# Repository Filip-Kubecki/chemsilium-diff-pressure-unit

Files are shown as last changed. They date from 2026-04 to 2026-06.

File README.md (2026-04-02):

# Pressure Measurement Unit - Chemsilium

A differential pressure acquisition system developed for the **Chemsilium Science Club**. This project integrates a **BMP280** (for ambient barometric pressure as calibration point) and dual *MPXM2202GS/AS* setup for differential pressure measurement.

## Repository Structure

The project is organized into four main branches to ensure maintainability:

* **`/hardware`**: Contains **KiCad** PCB and electronic design files.
  <!-- * `sch/`: Schematic diagrams. -->
  <!-- * `pcb/`: Board layout and routing. -->
  <!-- * `fabrication/`: Production-ready Gerbers, BOM (Bill of Materials), and CPL files. -->
* **`/firmware`**: Source code for the **Arduino/C++** embedded system.
  * Handles I2C communication with sensors.
  * Manages data packet formatting for serial transmission (using UART).
* **`/software`**: Desktop application scripts for data visualization and logging.
  * Real-time graphing of pressure trends.
  * CSV logging for post-experimental analysis.
* **`/docs`**: Technical documentation, including user manual with setup, maintenance and use explanations.

---

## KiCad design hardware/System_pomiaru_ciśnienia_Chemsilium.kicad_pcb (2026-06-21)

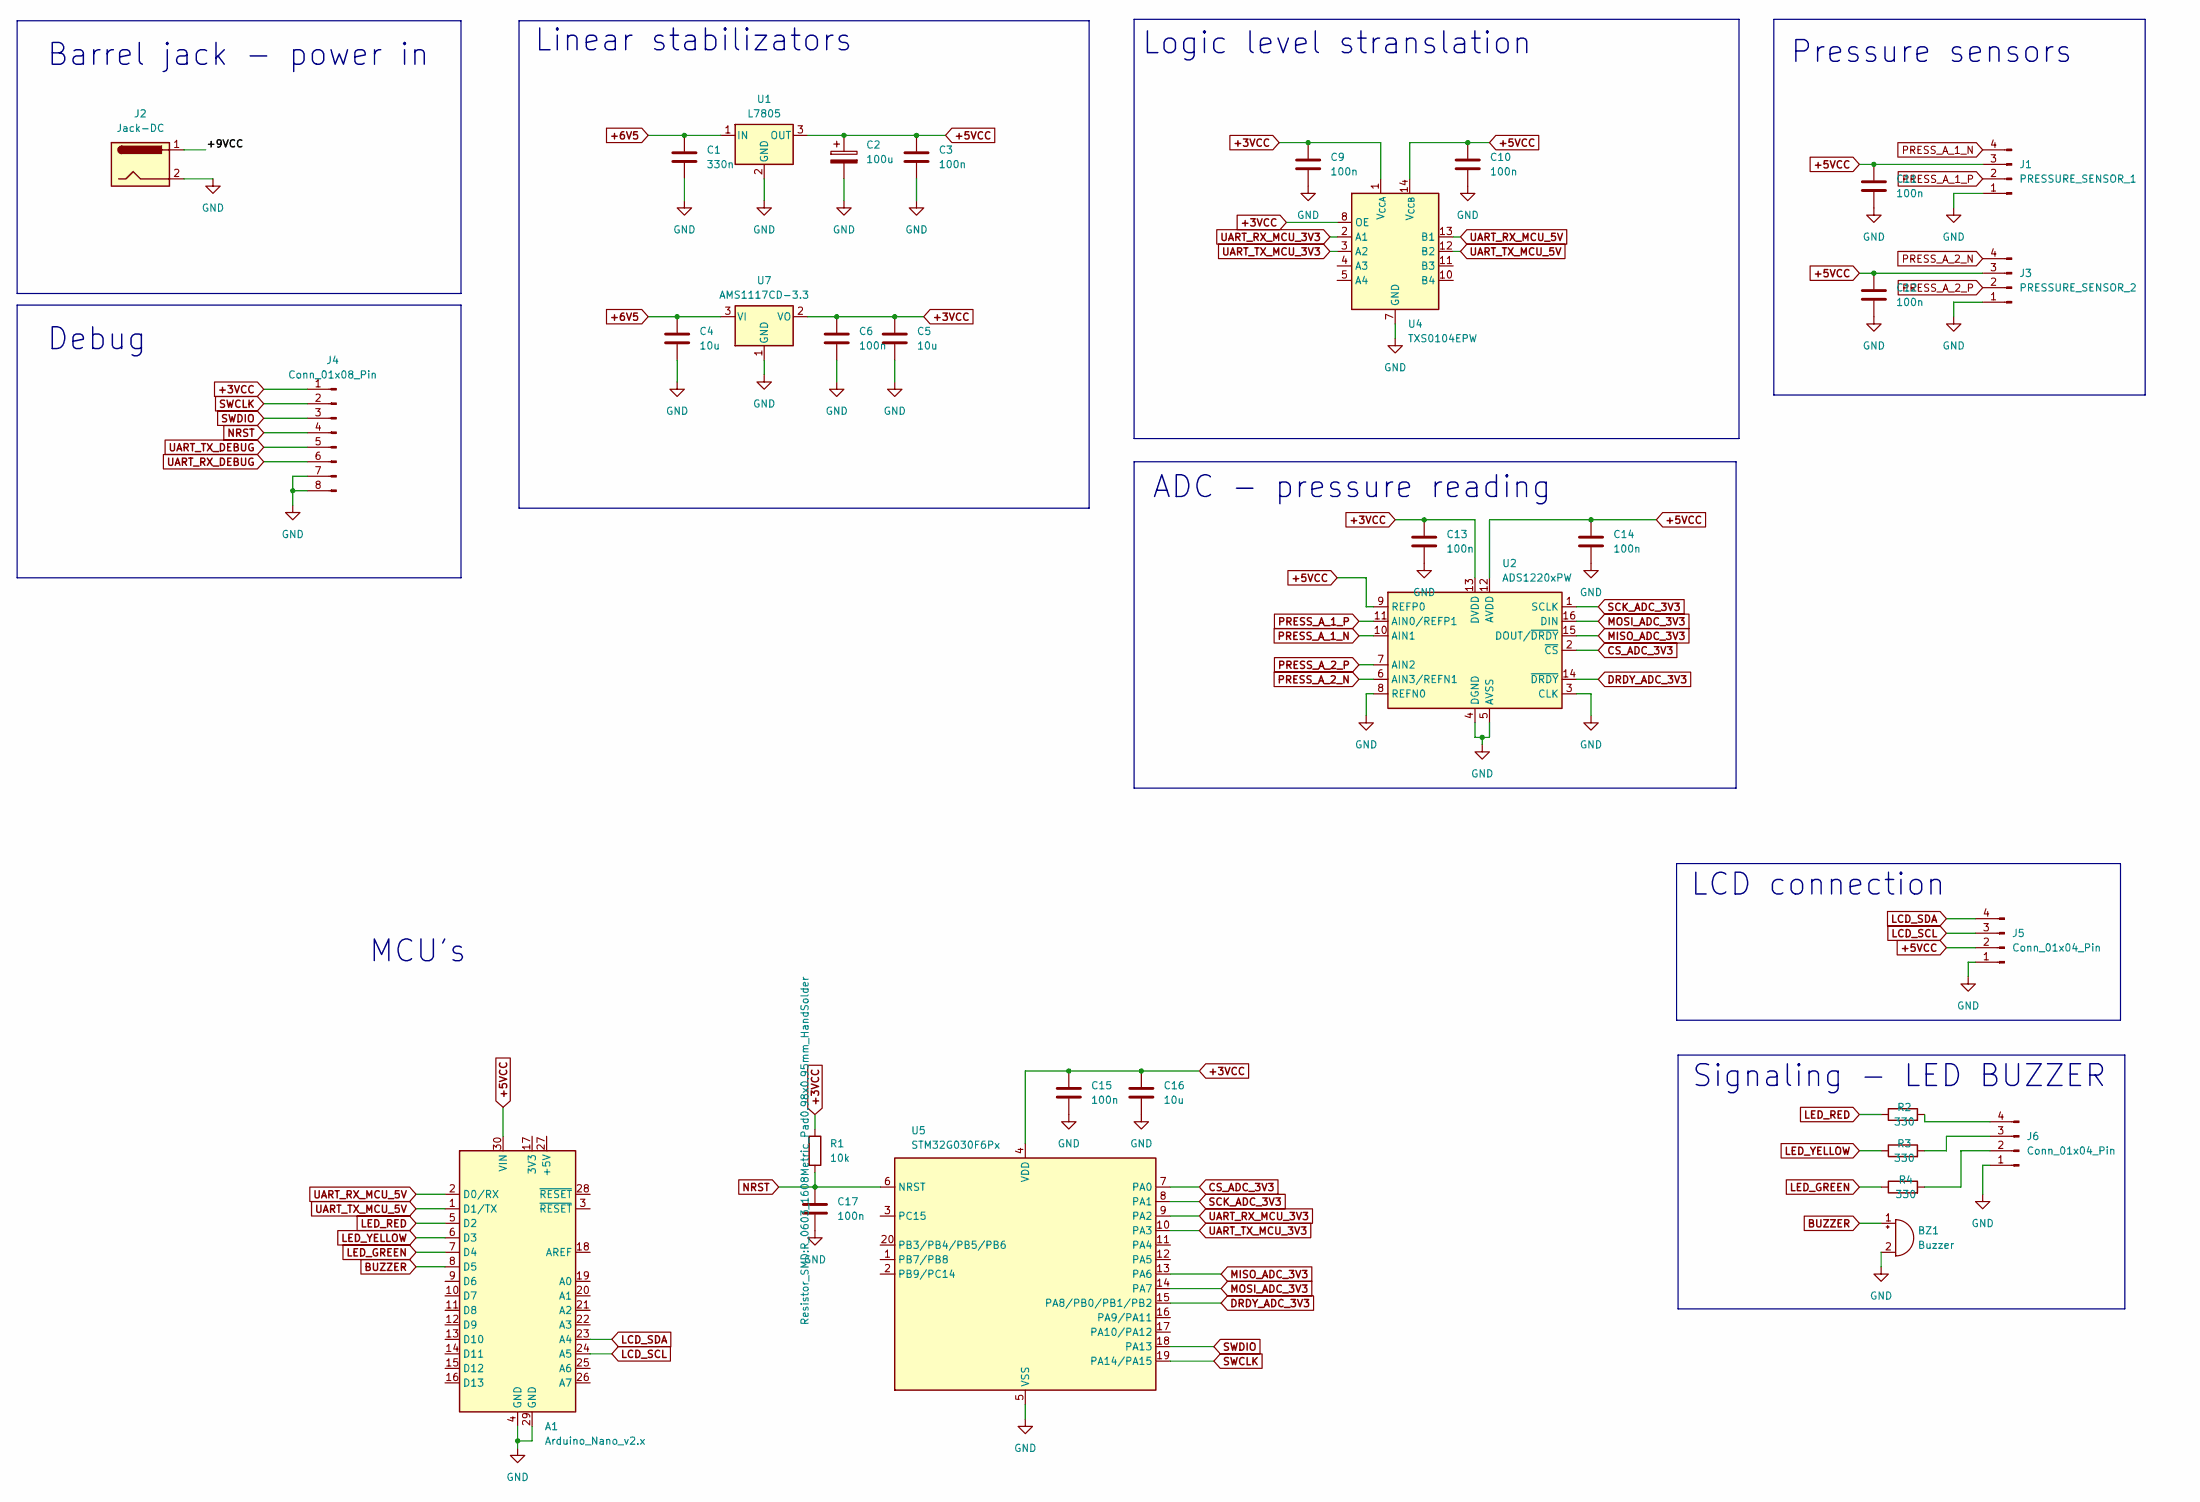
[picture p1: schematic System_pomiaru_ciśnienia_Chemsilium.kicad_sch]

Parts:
A1: Arduino_Nano_v2.x; Arduino_Nano
BZ1: Buzzer; Buzzer_12x9.5RM7.6
C1: 330n; CP_Radial_Tantal_D4.5mm_P2.50mm
C2: 100u; CP_Radial_D8.0mm_P3.80mm
C3, C6, C9, C10, C11, C12, C13, C14, C15, C17: 100n; C_0603_1608Metric_Pad1.08x0.95mm_HandSolder
C4, C5, C16: 10u; C_0805_2012Metric_Pad1.18x1.45mm_HandSolder
J1: PRESSURE_SENSOR_1; mpx2202
J2: Jack-DC; BarrelJack_CUI_PJ-102AH_Horizontal
J3: PRESSURE_SENSOR_2; mpx2202
J4: Conn_01x08_Pin; PinHeader_2x04_P2.54mm_Vertical
J5, J6: Conn_01x04_Pin; PinHeader_1x04_P2.54mm_Vertical
R1: 10k; R_0603_1608Metric_Pad0.98x0.95mm_HandSolder
R2, R3, R4: 330; R_Axial_DIN0207_L6.3mm_D2.5mm_P2.54mm_Vertical
U1: L7805; TO-220-3_Vertical
U2: ADS1220xPW; TSSOP-16_4.4x5mm_P0.65mm
U4: TXS0104EPW; TSSOP-14_4.4x5mm_P0.65mm
U5: STM32G030F6Px; TSSOP-20_4.4x6.5mm_P0.65mm
U7: AMS1117CD-3.3; TO-252-3_TabPin2

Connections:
+3VCC: C5.1, C6.1, C9.1, C13.1, C15.1, C16.1, J4.1, R1.1, U2.13 (DVDD), U4.1 (V_{CCA}), U4.8 (OE), U5.4 (VDD), U7.2 (VO)
+5VCC: A1.30 (VIN), C2.1, C3.1, C10.1, C11.1, C12.1, C14.1, J1.3, J3.3, J5.2, U1.3 (OUT), U2.9 (REFP0), U2.12 (AVDD), U4.14 (V_{CCB})
+6V5: C1.1, C4.1, U1.1 (IN), U7.3 (VI)
/+9VCC: J2.1
BUZZER: A1.8 (D5), BZ1.1 (+)
CS_ADC_3V3: U2.2 (~CS), U5.7 (PA0)
DRDY_ADC_3V3: U2.14 (~DRDY), U5.15 (PA8/PB0/PB1/PB2)
GND: A1.4 (GND), A1.29 (GND), BZ1.2 (-), C1.2, C2.2, C3.2, C4.2, C5.2, C6.2, C9.2, C10.2, C11.2, C12.2, C13.2, C14.2, C15.2, C16.2, C17.2, J1.1, J2.2, J3.1, J4.7, J4.8, J5.1, J6.1, U1.2 (GND), U2.3 (CLK), U2.4 (DGND), U2.5 (AVSS), U2.8 (REFN0), U4.7 (GND), U5.5 (VSS), U7.1 (GND)
LCD_SCL: A1.24 (A5), J5.3
LCD_SDA: A1.23 (A4), J5.4
LED_GREEN: A1.7 (D4), R4.1
LED_RED: A1.5 (D2), R2.1
LED_YELLOW: A1.6 (D3), R3.1
MISO_ADC_3V3: U2.15 (DOUT/~DRDY), U5.13 (PA6)
MOSI_ADC_3V3: U2.16 (DIN), U5.14 (PA7)
NRST: C17.1, J4.4, R1.2, U5.6 (NRST)
unnamed: J6.2, R4.2
unnamed: J6.3, R3.2
unnamed: J6.4, R2.2
PRESS_A_1_N: J1.4, U2.10 (AIN1)
PRESS_A_1_P: J1.2, U2.11 (AIN0/REFP1)
PRESS_A_2_N: J3.4, U2.6 (AIN3/REFN1)
PRESS_A_2_P: J3.2, U2.7 (AIN2)
SCK_ADC_3V3: U2.1 (SCLK), U5.8 (PA1)
SWCLK: J4.2, U5.19 (PA14/PA15)
SWDIO: J4.3, U5.18 (PA13)
UART_RX_DEBUG: J4.6
UART_RX_MCU_3V3: U4.2 (A1), U5.9 (PA2)
UART_RX_MCU_5V: A1.2 (D0/RX), U4.13 (B1)
UART_TX_DEBUG: J4.5
UART_TX_MCU_3V3: U4.3 (A2), U5.10 (PA3)
UART_TX_MCU_5V: A1.1 (D1/TX), U4.12 (B2)

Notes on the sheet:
Linear stabilizators
LCD connection
Pressure sensors
Debug
MCU's
ADC - pressure reading
Barrel jack - power in
Signaling - LED BUZZER
Logic level stranslation

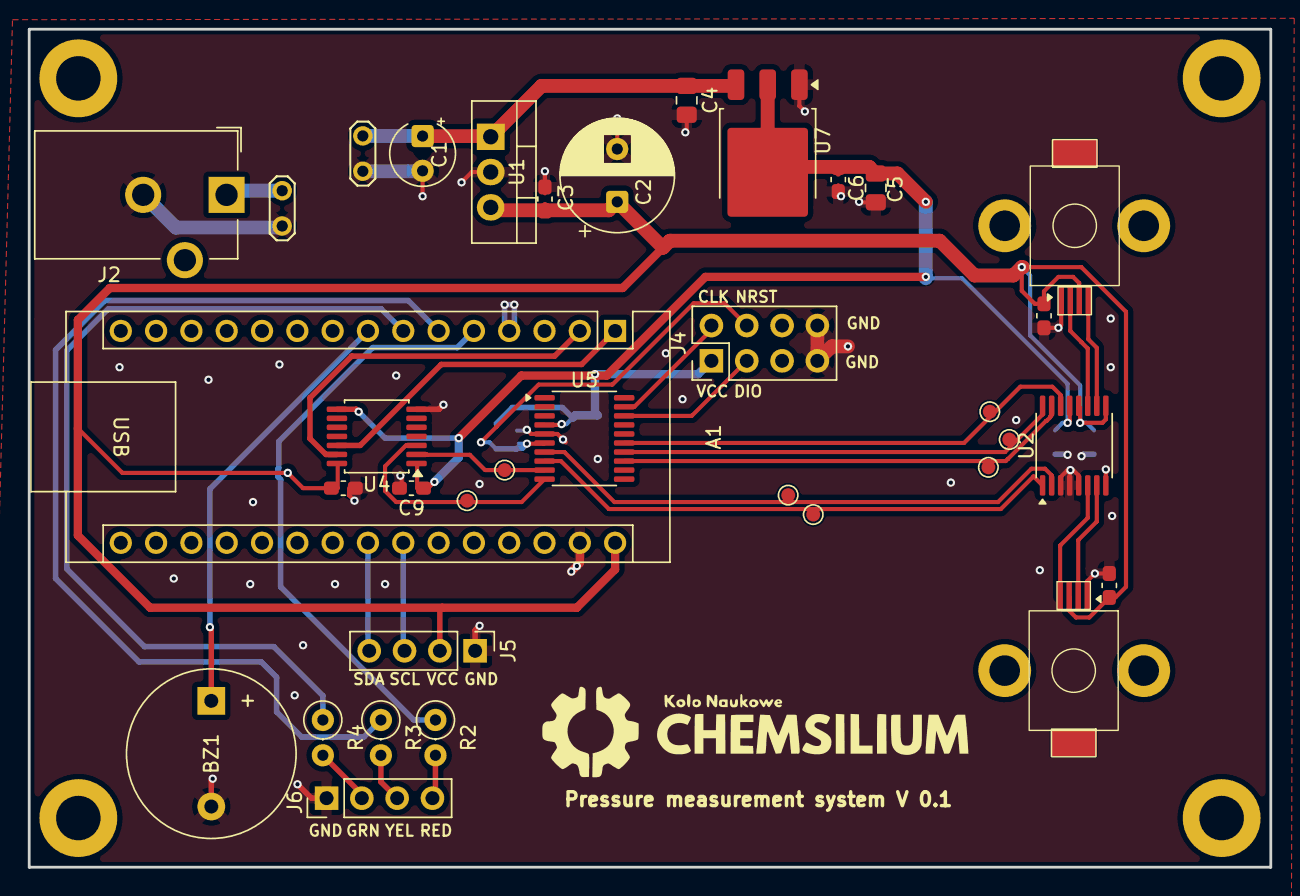
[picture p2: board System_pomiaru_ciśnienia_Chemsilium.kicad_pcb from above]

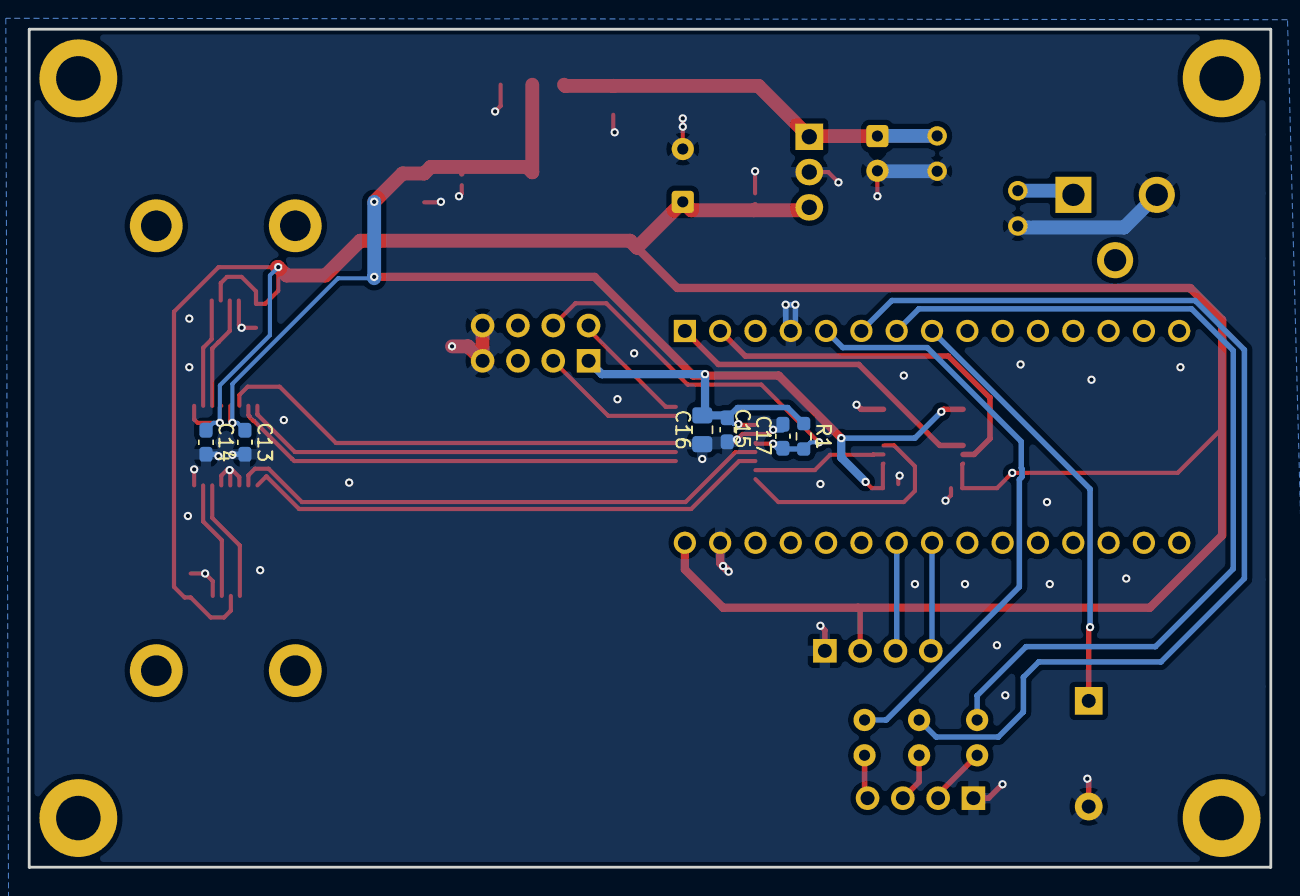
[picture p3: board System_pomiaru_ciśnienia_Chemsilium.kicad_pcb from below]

Board: 2 copper layers, 89.3 x 60.3 mm, 32 parts (6 on the bottom side), 29 nets.

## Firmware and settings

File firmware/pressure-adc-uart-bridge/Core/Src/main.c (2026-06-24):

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
/* Includes ------------------------------------------------------------------*/
#include "main.h"

/* USER CODE BEGIN Includes */
  #include <string.h>
  #include <stdlib.h>

  #include "ADS1220IPWR.h"
/* USER CODE END Includes */

SPI_HandleTypeDef hspi1;

UART_HandleTypeDef huart2;

void SystemClock_Config(void);
static void MX_GPIO_Init(void);
static void MX_USART2_UART_Init(void);
static void MX_SPI1_Init(void);
/* USER CODE BEGIN 0 */

  void Send24BitPacket(uint32_t ch1, uint32_t ch2) {
      uint8_t frame[10];
      
      frame[0] = 0xDE;
      frame[1] = 0xAD;
      
      frame[2] = (uint8_t)(ch1 >> 16);
      frame[3] = (uint8_t)(ch1 >> 8);
      frame[4] = (uint8_t)(ch1);
      
      frame[5] = (uint8_t)(ch2 >> 16);
      frame[6] = (uint8_t)(ch2 >> 8);
      frame[7] = (uint8_t)(ch2);
      
      frame[8] = 0xBE;
      frame[9] = 0xEF;
      
      HAL_UART_Transmit(&huart2, frame, 10, 100);
  }
/* USER CODE END 0 */

/**
  * @brief  The application entry point.
  * @retval int
  */
int main(void)
{

  /* MCU Configuration--------------------------------------------------------*/

  /* Reset of all peripherals, Initializes the Flash interface and the Systick. */
  HAL_Init();

  /* Configure the system clock */
  SystemClock_Config();

  /* Initialize all configured peripherals */
  MX_GPIO_Init();
  MX_USART2_UART_Init();
  MX_SPI1_Init();
  /* USER CODE BEGIN 2 */

  srand(HAL_GetTick());

  ADS1220_Init(&hspi1);
  ADS1220_Reset();
  ADS1220_Configure();

  /* USER CODE END 2 */

  /* Infinite loop */
  /* USER CODE BEGIN WHILE */
  while (1)
  {
    /* USER CODE END WHILE */

    /* USER CODE BEGIN 3 */
    int32_t raw_ch1 = 0, raw_ch2 = 0;

    ADS1220_SelectChannel(ADS1220_CHANNEL_1);
    if (ADS1220_WaitForData(20) == HAL_OK) {
        raw_ch1 = ADS1220_ReadData();
    }

    ADS1220_SelectChannel(ADS1220_CHANNEL_2);
    if (ADS1220_WaitForData(20) == HAL_OK) {
        raw_ch2 = ADS1220_ReadData();
    }

    float voltage_ch1_mV = ADS1220_RawToVoltage_mV(raw_ch1);
    float voltage_ch2_mV = ADS1220_RawToVoltage_mV(raw_ch2);

    float pressure_ch1_Pa = ADS1220_VoltageToPressure_Pa(voltage_ch1_mV);
    float pressure_ch2_Pa = ADS1220_VoltageToPressure_Pa(voltage_ch2_mV);

    Send24BitPacket((uint32_t)pressure_ch1_Pa, (uint32_t)pressure_ch2_Pa);
    HAL_Delay(1);
  }
  /* USER CODE END 3 */
}

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


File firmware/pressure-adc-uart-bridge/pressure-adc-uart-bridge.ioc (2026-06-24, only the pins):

Mcu.UserName=STM32G030F6Px
PA0.GPIO_Label=SPI1_CS
PA0.Signal=GPIO_Output
PA1.Signal=SPI1_SCK
PA2.Signal=USART2_TX
PA3.Signal=USART2_RX
PA6.Signal=SPI1_MISO
PA7.Signal=SPI1_MOSI
PB0.Signal=GPIO_Input

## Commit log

2026-04-02 [POC] Basic measurement for MX2202 with "calibration"
    Backup of old files used for fast check of MXP2202 sensor.
2026-04-02 [POC] Backup of test PCB for MPX2202 developement
    This PCB is prototype used for ease of testing MPX2202 sensors. Board
    already has differential path for analog outputs and ADS1X015 mounted on
    it. It is easy to etch in home design.
    [System_pomiaru_ciśnienia_Chemsilium.kicad_pcb, System_pomiaru_ciśnienia_Chemsilium.kicad_sch]
2026-06-21 [feat] Initial test design for differential pressure sensor PCB
    Initial PCB prototype for differential pressure measurement device.
    Identified issues for future iterations:
    - UART conflict between STM32 and Arduino Nano.
    - Incorrect footprint for MPXM2202 sensor (pitch too small).
    - Missing dedicated header for BMP280.
    - Insufficient expansion pins (GPIOs for encoder).
    - Integrated step-down converter requirement (current version lacks
    onboard integration).
    [System_pomiaru_ciśnienia_Chemsilium.kicad_pcb, System_pomiaru_ciśnienia_Chemsilium.kicad_sch]
2026-06-22 [feat] Add STM32-to-Arduino data bridge and ADS1220 driver
    Implemented complete firmware for STM32G030F6 to interface with two
    pressure sensors via ADS1220 ADC. Features include SPI communication for
    sensor data acquisition and UART transmission to forward processed
    pressure values to an Arduino Nano.
2026-06-24 [feat] Improved data transmission for STM32

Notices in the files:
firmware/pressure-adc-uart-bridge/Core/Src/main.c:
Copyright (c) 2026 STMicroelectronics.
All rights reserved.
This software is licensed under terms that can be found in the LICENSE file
